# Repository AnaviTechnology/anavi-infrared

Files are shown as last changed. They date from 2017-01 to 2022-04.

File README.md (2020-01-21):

# ANAVI Infrared pHAT

ANAVI Infrared pHAT is an open source hardware Raspberry Pi pHAT (add-on board) for rapid prototyping of Internet of Things (IoT) powered by free and open source software. It features:

* 2x IR transmitters
* IR receiver (IR photo sensor)
* Slots for up to 3 plug and play I2C sensors for temperature, barometric pressure, humidity and light
* UART (Universal asynchronous receiver/transmitter) pins for debugging

ANAVI Infrared pHAT is available at [CrowdSupply](https://www.crowdsupply.com/anavi-technology/infrared-phat).

# License

The project is released under the [Creative Commons Attribution-ShareAlike 4.0 International (CC BY-SA 4.0)](https://creativecommons.org/licenses/by-sa/4.0/).

Note: This is a human-readable summary of (and not a substitute for) the [license](https://creativecommons.org/licenses/by-sa/4.0/legalcode).

You are free to:

Share — copy and redistribute the material in any medium or format Adapt — remix, transform, and build upon the material for any purpose, even commercially. The licensor cannot revoke these freedoms as long as you follow the license terms. Under the following terms:

Attribution — You must give appropriate credit, provide a link to the license, and indicate if changes were made. You may do so in any reasonable manner, but not in any way that suggests the licensor endorses you or your use. ShareAlike — If you remix, transform, or build upon the material, you must distribute your contributions under the same license as the original. No additional restrictions — You may not apply legal terms or technological measures that legally restrict others from doing anything the license permits. Notices:

You do not have to comply with the license for elements of the material in the public domain or where your use is permitted by an applicable exception or limitation. No warranties are given. The license may not give you all of the permissions necessary for your intended use. For example, other rights such as publicity, privacy, or moral rights may limit how you use the material.

You will have to provide a link to the original creator of the project http://www.anavi.technology on any documentation or website.

Credit can be attributed through a link to the creator website: http://www.anavi.technology

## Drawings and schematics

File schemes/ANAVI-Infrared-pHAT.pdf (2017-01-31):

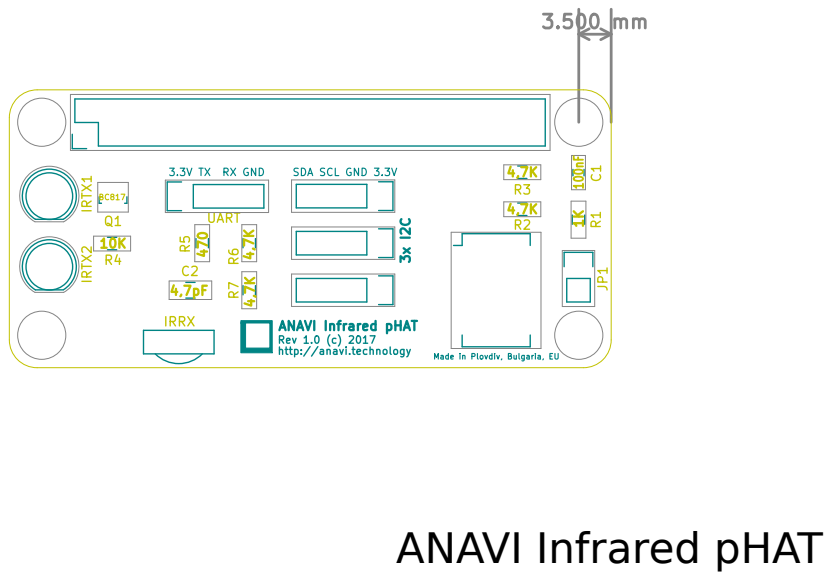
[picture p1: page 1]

ANAVI Infrared pHAT

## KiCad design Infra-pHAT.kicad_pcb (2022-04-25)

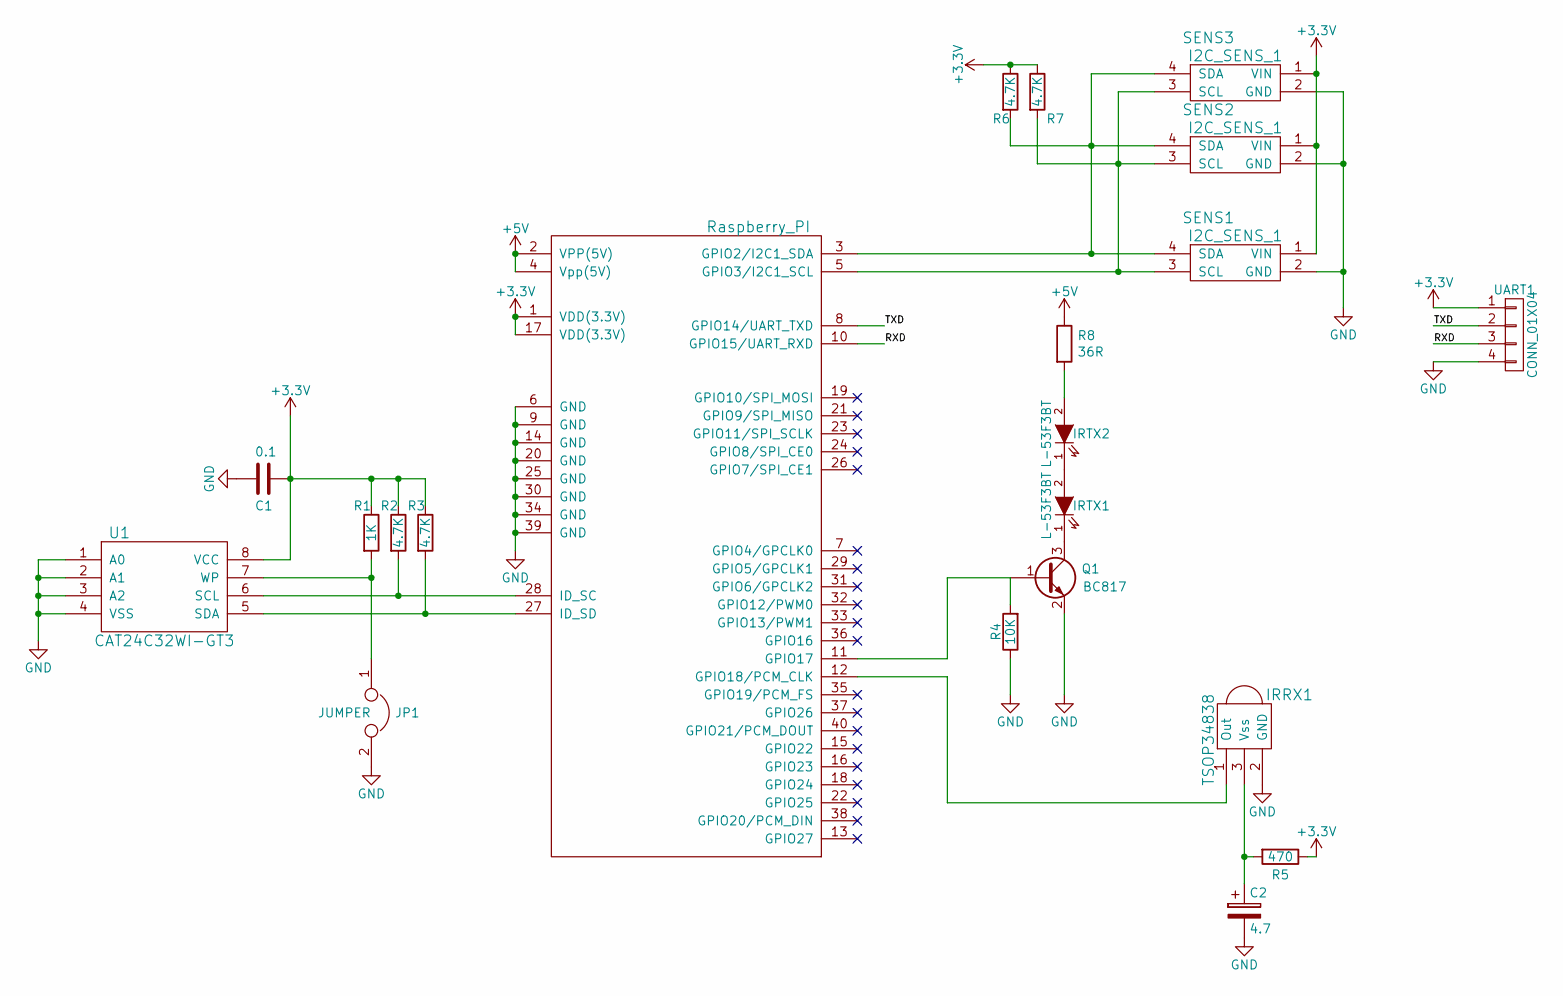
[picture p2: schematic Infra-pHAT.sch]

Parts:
C1: 0.1; C_0603_HandSoldering
C2: 4.7; C_0805_HandSoldering
IRRX1: TSOP34838; TSOP38X
IRTX1, IRTX2: L-53F3BT; LED-5MM
JP1: JUMPER; Pin_Header_Straight_1x02
Q1: BC817; SOT-23
R1: 1K; R_0603_HandSoldering
R2, R3, R6, R7: 4.7K; R_0603_HandSoldering
R4: 10K; R_0603_HandSoldering
R5: 470; R_0603_HandSoldering
R8: 36R; R_0603_HandSoldering
RASP_CONN1: Raspberry_PI; Pin_Header_Straight_2x20
SENS1, SENS2, SENS3: I2C_SENS_1; Pin_Header_Straight_1x04
U1: CAT24C32WI-GT3; DIP-8_W7.62mm
UART1: CONN_01X04; Pin_Header_Straight_1x04

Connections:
+3V3: C1.1, R1.1, R2.1, R3.1, R5.1, R6.1, R7.1, RASP_CONN1.1 (VDD(3.3V)), RASP_CONN1.17 (VDD(3.3V)), SENS1.1 (VIN), SENS2.1 (VIN), SENS3.1 (VIN), U1.8 (VCC), UART1.1; also elsewhere on the board
+5V: R8.1, RASP_CONN1.2 (VPP(5V)), RASP_CONN1.4 (Vpp(5V))
/RXD: RASP_CONN1.10 (GPIO15/UART_RXD), UART1.3; also elsewhere on the board
/TXD: RASP_CONN1.8 (GPIO14/UART_TXD), UART1.2; also elsewhere on the board
GND: C1.2, C2.2, IRRX1.2 (GND), JP1.2, Q1.2 (E), R4.1, RASP_CONN1.6 (GND), RASP_CONN1.9 (GND), RASP_CONN1.14 (GND), RASP_CONN1.20 (GND), RASP_CONN1.25 (GND), RASP_CONN1.30 (GND), RASP_CONN1.34 (GND), RASP_CONN1.39 (GND), SENS1.2 (GND), SENS2.2 (GND), SENS3.2 (GND), U1.1 (A0), U1.2 (A1), U1.3 (A2), U1.4 (VSS), UART1.4; also elsewhere on the board
unnamed: C2.1, IRRX1.3 (Vss), R5.2
unnamed: IRRX1.1 (Out), RASP_CONN1.12 (GPIO18/PCM_CLK)
unnamed: IRTX1.1 (K), Q1.3 (C)
unnamed: IRTX1.2 (A), IRTX2.1 (K)
unnamed: IRTX2.2 (A), R8.2
unnamed: JP1.1, R1.2, U1.7 (WP)
unnamed: Q1.1 (B), R4.2, RASP_CONN1.11 (GPIO17)
unnamed: R2.2, RASP_CONN1.28 (ID_SC), U1.6 (SCL)
unnamed: R3.2, RASP_CONN1.27 (ID_SD), U1.5 (SDA)
unnamed: R6.2, RASP_CONN1.3 (GPIO2/I2C1_SDA), SENS1.4 (SDA), SENS2.4 (SDA), SENS3.4 (SDA)
unnamed: R7.2, RASP_CONN1.5 (GPIO3/I2C1_SCL), SENS1.3 (SCL), SENS2.3 (SCL), SENS3.3 (SCL)

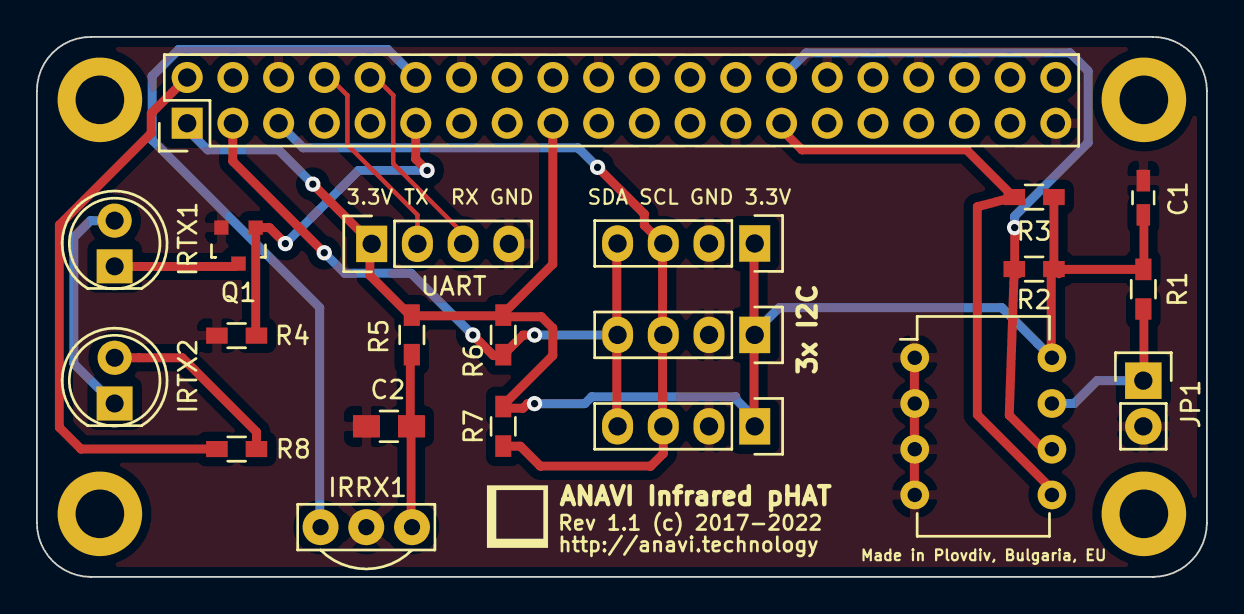
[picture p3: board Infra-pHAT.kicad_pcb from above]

Board: 2 copper layers, 65.0 x 30.0 mm, 25 parts (0 on the bottom side), 16 nets.

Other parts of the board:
REF1, REF2, REF3, REF4: MountingHole_2.7mm_M2.5_DIN965_Pad
UART: CONN_01X04; Pin_Header_Straight_1x04

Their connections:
+3V3: UART.1; also elsewhere on the board
/RXD: UART.3; also elsewhere on the board
/TXD: UART.2; also elsewhere on the board
GND: UART.4; also elsewhere on the board

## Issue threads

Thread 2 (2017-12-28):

Stray uart input with hat connected and rx pin left disconnected

robsee, 2017-12-28:
I ran into in an issue with the uart passthrough from the hat. When RX on the hat is left disconnected, and UART support is enabled, there is some interference that is getting passed through as key presses. I originally discovered this using the ubuntu pi distribution, when it wouldn't boot because uboot autoboot was getting interruped by these "key presses". Either connecting the rx pin, or disabling uart support in config.txt are work arounds. To reproduce, enable_uart=1 in config.txt and connect only the tx pin and the gnd to a usb ttl serial adapter.

leon-anavi, 2017-12-30:
Hi @robsee,

Thank you very much for reporting this issue as well as for the further feedback provided over the email. I will have it in mind and try find a solution in the next hardware release.

Best regards,
Leon

tyeth, 2021-04-20:
I know floating pins are usually bad or at least act like aerials for noise, but did you find a solution, or is it only possible with a tiny resistor to avoid the floating status / errors?

leon-anavi, 2021-04-20:
Hi @tyeth,

No, we haven't released new hardware version. Yes, probably a resistor may improve the situation. If you experience any issues caused by this please apply the described work around by either connecting the RX pin, or disabling UART support from the software side.

Best regards,
Leon

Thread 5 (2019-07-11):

Any recommendations for cases?

mike-mo, 2019-07-11:
It would be awesome to compile some case recommendations for this hat.

Is the location of the IRRX a challenge for full-size Pi cases? Has anyone found a case that is easily moddable to acommodate the LEDs and I2C sensors? Perhaps someone has a custom 3D-printed case that fits this well?

Please do share!

leon-anavi, 2019-07-11:
Hi @mike-mo,

The official Pi Cases aren't a good fit for ANAVI Infrared pHAT, at least not without some modifications because the two infrared LEDs have to be out of the box. [Pimoroni PiBow cases are a decent but not perfect option](https://shop.pimoroni.com/collections/pibow). For Raspberry Pi Zero and Zero W I have shared 3D design of a simple case that anyone can print. It is available at GitHub https://github.com/AnaviTechnology/anavi-cases/tree/master/rpi0-anavi-infrared-case

Thanks,
Leon

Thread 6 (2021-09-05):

Feature Request: Move IR Tx to a hardware PWM capable pin

normanr, 2021-09-05:
If you spin another hardware revision it would be nice if the IR Tx could be moved to a PWM capable pin. Pin 12 (BCM GPIO 18) is one of the few ports that support hardware PWM, so just switching the RX and TX pins would do, and would be pretty easy as their traces run very close to each other on the board, and would be easy to manually reroute.

leon-anavi, 2021-09-06:
Hi @normanr,

This is a great idea for an improvement! Thank you for the feedback. The only thing that worries me is that it may create confusion among users of the current and the potential new hardware revision.

Eventually, it may be worth doing this on a new HAT (with the full HAT size) with some additional features.

Thanks,
Leon

normanr, 2021-09-06:
Yes, I considered the confusion. I think if the board is clearly marked with Rev 2.0, and it's documented, then maybe it would be okay. Another alternative would be to use pin 32/33/35 (the other PWM pins), maybe with a jumper (or solder bridge?) to select between pin 11 and the PWM capable pin.

While I've swapped pin 11 and 12 with some rework, I haven't yet switched to the pwm-ir-tx driver, so I'm still using the gpio-ir-tx driver which just bit-bangs the output. So I have yet to measure the performance difference that swapping the pins enables.

fwiw one of the reasons why I love the ANAVI Infrared pHAT was that it was the same size as the Pi Zero. About the only thing lacking I've found is a 5V output, as I'm looking to connect a PMS5003 to it, and it requires 5V power with 3V3 UART (currently connected via a FTDI TTL-232-3V3 cable).

leon-anavi, 2021-09-13:
Hi @normanr,

Using a jumper is a wonderful idea because it will allow swapping the GPIOs without any soldering. Adding 5V next to the 3.3V to the UART header is also a great idea and easy to do. Both definitely makes sense for rev 2.0.

As of the moment I am not familiar with the `pwm-ir-tx` drive. Could you please provide feedback if you have a chance to give it a try in the future?

Thanks again for the feedback and sharing these great ideas for improvements.

Thanks,
Leon

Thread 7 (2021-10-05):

LED driver current

normanr, 2021-10-05:
I was trying to figure out what the current through the IR LEDs is, and I think that there might be a missing current limiting resistor (or two).

If I assume that the IR led is being driven at 38kHz at 50% duty, then pulse width is around 13us. The TSAL6400 datasheet indicates that limits would be ~220mA, and maybe ~1.5V? The BC817 has a Vcesat of 0.7V, so that's still ~1.3V (5V - 2*1.5V - 0.7V) unaccounted for. Working backwards ((5V - 0.7V)/2) if the LEDs were driving at 2.15V, that would draw about 900mA, which is also concerning because peak forward current is rated at 200mA (for tp/T=0.5).

Of course LED current should also be limited by the transistor (and it's hFE), but I also get stuck trying to work out what Ic for BC817 would be, because I can't figure out Ib: Vbe is typically 1.2V, but the GPIO will try and drive the pin at 3.3V, so there's approximately 2V unaccounted for there. The default pad drive current is 8mA, but that's not a limit, only a "guarantee" to drive at 3.0V if current is less than configured drive (https://www.raspberrypi.org/documentation/computers/raspberry-pi.html#voltage-specifications). It's not clear what the pad max current is, but the table lists 17mA at 2.3V, so (with an hFE of 40) Ic could be as high as 680mA.

In the worse case maybe the 5V rail is being pulled to ~3.7V while the LED is on, and the power supply is the limit? That would mean max current of ~1A, and maybe nothing on the 3.3V supply cares because 3.7V might still be enough to supply the 3.3V regulator? I don't have a scope to be able to check anything, and I don't think a multimeter will be sufficient because of the low pulse duration (and I don't want to just enable the pin to measure the steady state "on" values, because they're likely to be way over spec).

leon-anavi, 2021-10-05:
Hi @normanr,

Yes, probably it makes sense to add current limiting resistor to the schematics. I confirm a multimeter won't be very useful in this case for measurements because of the very fast infrared bursts during data transmission.

Btw the infrared LEDs are [5mm KINGBRIGHT L-53F3BT](https://store.comet.bg/download-file.php?id=1009).

Best regards,
Leon

leon-anavi, 2022-04-20:
Hi @normanr,

Following your recommendation I have added a 220ohm current limiting resistor for the IR LEDs: https://github.com/AnaviTechnology/anavi-infrared/commit/e47de9f4795c4e42111bb9e3bb92814f7cb4815f

Best regards,
Leon

normanr, 2022-04-21:
What current do you get with 220Ω? At a rough guess I think it's less than 10mA.

leon-anavi, 2022-04-21:
> What current do you get with 220Ω? At a rough guess I think it's less than 10mA.

Honestly, it was late night and I put a template value without looking at the datasheet. So probably it should be 36Ω.

* L-53F3BT max forward voltage is 1.6V.
* L-53F3BT current is 50mA (0.05A).
* There 2 LEDs connected in series to 5V rail in so my calculation based on Ohm's law: (5V - 1.6V * 2) / 0.05A = 36Ω

Is my calculation accurate? Am I missing anything?

Thanks,
Leon

normanr, 2022-04-23:
Yea, I've never sure if it should be max or typical forward voltage. Typical would give (5V - 1.2V * 2) / 0.05A = 52Ω.
I think you also need to take Vce(sat) of the BC817 into account, so maybe (5V - 1.2V * 2 - 0.7V) / 0.05A = 38Ω.

I searched for "5v dual ir led circuit BC817", and these articles seem interesting. I'm not sure that implementing a constant current driver is worth the extra components though. They also seem to use a much smaller resistor (but because they want to drive at around 200mA instead of 50mA, because they're using TSAL LEDs).
- https://arduinodiy.wordpress.com/2015/12/12/driving-an-ir-led-constant-current-source-or-not/
- https://forum.arduino.cc/t/best-ir-led-circuit/649245

Also you need to consider that resistors come in value series, so for something like E6, I guess 47Ω would be the choice. Going too high means that current will be lower and you'll get less luminous intensity, and buyers will complain that they're not as powerful. It's not clear what the effects of going to low are; certainly the v1 boards have zero resistance and seem to be working okay, but I'm not sure why.

You could try using a multi-meter with LEDs on solid 100% of the time, with a resistance starting with at least ~50Ω, and slowly decrease it measuring how the current responds.

Somewhere (I think [here](https://www.vishay.com/docs/80069/circuit.pdf)) I read that a shorter duty cycle can be advantageous because detectors care more about peak power output and not total power output (which is what the transmitting LED is more limited by). So shorter duty cycle, more current, same total power, but longer transmitting/detecting distance. With the Raspberry Pi I've found that very short duty cycles don't work very well, probably because the pulse isn't generated very cleanly, but I don't remember what the limits were.

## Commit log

2017-01-21 Infra-pHAT.kicad_pcb: Adjust positions
    [Infra-pHAT.kicad_pcb]
2017-01-21 Infra-pHAT.kicad_pcb: Update settings
    Increase traces and vias.
    [Infra-pHAT.kicad_pcb]
2017-01-21 Infra-pHAT.kicad_pcb: Rearange components
    [Infra-pHAT.kicad_pcb]
2017-01-21 Infra-pHAT.kicad_pcb: Fix edge cuts
    [Infra-pHAT.kicad_pcb]
2017-01-21 Infra-pHAT.kicad_pcb: make space for tracing
    [Infra-pHAT.kicad_pcb]
2017-01-22 Infra-pHAT.kicad_pcb: Roteate UART
    [Infra-pHAT.kicad_pcb]
2017-01-22 Infra-pHAT.kicad_pcb: Route EEPROM
    [Infra-pHAT.kicad_pcb]
2017-01-22 Infra-pHAT.kicad_pcb: Route I2C slots
    [Infra-pHAT.kicad_pcb]
2017-01-22 Infra-pHAT.kicad_pcb: Route IR LED
    [Infra-pHAT.kicad_pcb]
2017-01-22 Infra-pHAT.kicad_pcb: Fix holes numbering
    Fix the numbering of the pads of the the mounting
    holes.
    [Infra-pHAT.kicad_pcb]
2017-01-22 Infra-pHAT.kicad_pcb: Route for IR RX
    [Infra-pHAT.kicad_pcb]
2017-01-22 Fix position of mounting holes and pin header
    Fix wiring of transistor for IR leds
    [Infra-pHAT.kicad_pcb, Infra-pHAT.sch]
2017-01-22 Add filled zone for front layer (GND net)
    Route RX/TX for UART connector
    [Infra-pHAT.kicad_pcb, Infra-pHAT.sch]
2017-01-22 Infra-pHAT.kicad_pcb: Update routing
    [Infra-pHAT.kicad_pcb]
2017-01-22 Infra-pHAT.kicad_pcb: Silkscreen text added
    [Infra-pHAT.kicad_pcb]
2017-01-22 Add logo and update tesxt on the silkscreen
    [Infra-pHAT.kicad_pcb]
2017-01-22 Infra-pHAT.kicad_pcb: Add revision number
    [Infra-pHAT.kicad_pcb]
2017-01-22 Infra-pHAT.kicad_pcb: Increase text size
    [Infra-pHAT.kicad_pcb]
2017-01-22 Update logo, texts and IRTX position
    [Infra-pHAT.kicad_pcb]
2017-01-23 Update name
    [Infra-pHAT.kicad_pcb]
2017-01-31 Infra-pHAT.kicad_pcb: Add assembly instructions
    [Infra-pHAT.kicad_pcb]
2018-03-25 README.md: CC BY-SA 4.0
    Switch license to CC BY-SA 4.0 because my newer
    open source hardware projects are with the same
    license.
2022-04-20 Infra-pHAT.pro: remap symbols
    Remap KiCad symbols.
    [Infra-pHAT.sch]
2022-04-22 Infra-pHAT.*: Add a current limiting resistor
    Add a current limiting resistor for the IR LEDs.
    Suggested-by: Norman Rasmussen <norman@rasmussen.co.za>
    [Infra-pHAT.kicad_pcb, Infra-pHAT.sch]
2022-04-25 Infra-pHAT.kicad_pcb: Update export rules
    Update configurations for exporting gerber and drill files.
    [Infra-pHAT.kicad_pcb]

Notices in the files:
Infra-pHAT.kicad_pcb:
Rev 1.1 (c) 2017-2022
